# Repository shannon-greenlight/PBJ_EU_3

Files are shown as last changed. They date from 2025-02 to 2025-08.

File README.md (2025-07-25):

# The PBJ EU
The PBJ EU is a hardware development system for Eurorack synthesizers

Features:
- 800 point solderless proto board
- 4 switched 3.5mm jacks.
- Tip and Switch signals are routed from the jacks to the wiring connector.
- +/- 12V and adjustable A and B power rails are routed to the wiring connector.
- LED monitors for each jack. Red indicates positive voltage. Green indicates negative.
- 2 Test points per jack gives convenient access for probing and injecting signals.
- 2 Large Ground connection points are excellent for attaching alligator clips.
- 3 MULT switches connect jack 1 to 2, jack 2 to 3 or jack 3 to 4.
- Power is switched.
- Power indicators show the status of all power rails.
- 22 HP wide.
- Ready when you are. Everything you need with no pre-setup required!

# Making Changes
The process of making changes usually starts with altering the schematic followed by other actions as required.
This requires a properly configured KiCAD installation. Download the KiCAD [repo](https://github.com/shannon-greenlight/KiCAD) and follow the instructions in the README to install.
When the system is configured follow the steps outlined below. Some steps are optional depending on what has changed.

These procedures have been optimized for use with Digi-Key and JLCPCB. They should be a good starting point for use with other vendors.

- Update schematic
	- Update revision in File->Page Settings
	- Plot pdf version of schematic.
- If any parts have changed, Update BOMs
	- From KiCAD Schematic Editor, run Tools->Generate Legacy Bill of Materials using bom2grouped_csv.xsl
		- bom2grouped_csv.xsl is found in the Greenface KiCAD repo.
		- Here is a sample command line: xsltproc -o "%O.csv" "C:\Users\shann\Dropbox\KiCAD\bom2grouped_csv.xsl" "%I"
		- This creates a .csv and an xml file. The xml file is used in the next step.
	- Run _combine_boms.bat_
		- This creates the following .csv files
			- BOM\Digi-Key\PBJ_EU_combined.csv (all components, both boards combined)
			- BOM\Digi-Key\PBJ_EU_full.csv (all components, top board)
			- BOM\Digi-Key\PBJ_EU_split.csv (just components on top board that are not found in LCSC BOM)
			- BOM\LCSC\PBJ_EU_bom.csv (just components on top board to be assembled by JLCPCB)
			- sub\BOM\Digi-Key\PBJ_EU_full.csv (all components, sub board)
			- sub\BOM\Digi-Key\PBJ_EU_split.csv (just components on sub board that are not found in LCSC BOM)
			- sub\BOM\LCSC\PBJ_EU_bom.csv (just components on sub board to be assembled by JLCPCB)
		- combine_boms.bat requires Python and the Greenface Python [libraries](https://github.com/shannon-greenlight/PYTHON_BOM) to be installed
			- Place the Greenface Python folder in a convienient place on your computer and set the variable %plugin_dir% to point to that folder location.
			- Python is invoked as 'py' in the batch file. This may need to be changed depending on your Python installation.
- Update layout if required
	- Update revision in File->Page Settings
	- Plot the Gerber files
		- Set the output directory to _fab\gerber\\_
		- Make sure to Generate Drill Files
		- Create a zip archive of the Gerber files. (This is required by JLCPCB)
			- Use Windows Send To Compressed Folder. Rename the resulting file to PBJ_EU_gerbers.zip
			- Alternatively, use zip_gerbers.bat
			- zip_gerbers.bat requires 7z.exe
			- Edit this file if 7z.exe is installed somewhere other than C:\Program Files\7-Zip
	- Create the pick-and-place files
		- From KiCAD PCB Editor, run File->Fabrication Outputs->Component Placement
		- Set the output directory to _fab\pos\\_
		- This creates the files used by the next step
		- Update PBJ_EU_cpl.xlsx
			- PBJ_EU_cpl.xlsx uses Excel Queries to convert pos\PBJ_EU-top-pos.csv into a format compatible with JLCPCB
			- Excel requires an absolute path to the source folder of the data. Edit the query to enter the path to your project.
			- *note: This process does not produce a perfect placement file due to differences in how KiCAD and JLCPCB orient components. However, JLCPCB is able to use the file without problems. So, even if the placement looks wrong when specifying the build, they will use the file and produce correct boards.
			- **note: There is probably a KiCAD plugin available that does a better job. The user is encouraged to try this route and report the results back.
- Upload to JLCPCB
	- JLCPCB requires the following files:
		- fab\PBJ_EU_gerbers.zip
		- fab\PBJ_EU_cpl.xlsx (only needed for assembly)
		- bom\LCSC\PBJ_EU_bom.csv (only needed for assembly)

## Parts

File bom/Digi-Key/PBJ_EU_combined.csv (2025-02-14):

Reference | Quantity | Value | Digi-Key Part #
B1, B2, | 2 | Breadboard_400 | 1286-1185-ND
RV1, RV2, | 2 | 5K | 3296W-502LF-ND
SC1, SC2, SC3, SC4, | 4 | Mounting Screw | 335-1156-ND
TP1, TP2, TP3, TP4, TP5, TP6, TP7, TP8, | 8 | TestPoint | 36-5006-ND
SW4, | 1 | MFS201N-9-Z | 563-1565-ND
SO1, SO2, SO3, SO4, SO5, SO6, SO7, SO8, | 8 | LED Spacer | 732-11596-ND
D11, | 1 | RED LED | 732-5005-ND
D9, | 1 | GREEN LED | 732-5007-ND
D10, | 1 | YELLOW LED | 732-5010-ND
D12, | 1 | BLUE LED | 732-5011-ND
D1, D3, D5, D7, | 4 | LED_RG | 754-WP937SURKCGKW-ND
SW1, SW2, SW3, | 3 | SW_SPDT | EG1248-ND
J5, | 1 | Conn_02x06_Odd_Even | S2211EC-06-ND
J6, | 1 | Conn_02x08_Odd_Even_Female | S7111-ND

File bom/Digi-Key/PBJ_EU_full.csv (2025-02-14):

Reference | Quantity | Value | Digi-Key Part #
B1, B2, | 2 | Breadboard_400 | 1286-1185-ND
J1, | 1 | Conn_02x06_Odd_Even | S5715-ND
J6, | 1 | Conn_02x08_Odd_Even_Female | S7111-ND
SC1, SC2, SC3, SC4, | 4 | Mounting Screw | 335-1156-ND
TP1, TP2, TP3, TP4, TP5, TP6, TP7, TP8, | 8 | TestPoint | 36-5006-ND

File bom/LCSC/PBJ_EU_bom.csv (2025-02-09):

Designator | Comment | Footprint | JLCPCBPart#
J1, | Conn_02x06_Odd_Even | greenface:PinSocket_2x06_P2.54mm_Vertical_SMD_no_holes | C3975151

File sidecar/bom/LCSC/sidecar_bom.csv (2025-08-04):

Designator | Comment | Footprint | JLCPCBPart#
J1, J2, J3, J4, | Conn_02x03_Odd_Even | Connector_PinSocket_2.54mm:PinSocket_2x03_P2.54mm_Vertical | C2897404

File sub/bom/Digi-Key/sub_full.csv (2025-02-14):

Reference | Quantity | Value | Digi-Key Part #
C1, C4, C6, C7, C11, C12, | 6 | 100nF | 311-1088-1-ND
C2, C5, | 2 | 10uF | 1276-6455-1-ND
C3, C8, | 2 | 22uF | 1276-7092-1-ND
C9, C10, C13, C14, | 4 | 10nF | 490-4778-1-ND
D1, D3, D5, D7, | 4 | LED_RG | 754-WP937SURKCGKW-ND
D9, | 1 | GREEN LED | 732-5007-ND
D10, | 1 | YELLOW LED | 732-5010-ND
D11, | 1 | RED LED | 732-5005-ND
D12, | 1 | BLUE LED | 732-5011-ND
J5, | 1 | Conn_02x06_Odd_Even | S2211EC-06-ND
J6, | 1 | Conn_02x05_Odd_Even | S9169-ND
R1, R2, R5, R6, | 4 | 620 | 13-MFR-25FTE52-620RCT-ND
R3, R4, | 2 | 2.2K | 541-10449-1-ND
R7, R9, R13, R15, | 4 | 510 | P17401CT-ND
R8, R10, R11, R12, R14, R16, R17, R18, | 8 | 1M | 541-2803-1-ND
RV1, RV2, | 2 | 5K | 3296W-502LF-ND
SO1, SO2, SO3, SO4, SO5, SO6, SO7, SO8, | 8 | LED Spacer | 732-11596-ND
SW1, SW2, SW3, | 3 | SW_SPDT | EG1248-ND
SW4, | 1 | MFS201N-9-Z | 563-1565-ND
U1, U3, | 2 | LM317 | 4518-LM317DCYRCT-ND
U2, U4, | 2 | TL072CDR | 296-1282-1-ND

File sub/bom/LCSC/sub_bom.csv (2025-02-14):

Designator | Comment | Footprint | JLCPCBPart#
C1, C4, C6, C7, C11, C12, | 100nF | Capacitor_SMD:C_0603_1608Metric | C14663
C2, C5, | 10uF | Capacitor_SMD:C_0805_2012Metric_Pad1.18x1.45mm_HandSolder | C15850
C3, C8, | 22uF | Capacitor_SMD:C_0805_2012Metric_Pad1.18x1.45mm_HandSolder | C76637
C9, C10, C13, C14, | 10nF | Capacitor_SMD:C_0603_1608Metric | C1589
J6, | Conn_02x05_Odd_Even | Connector_PinHeader_2.54mm:PinHeader_2x05_P2.54mm_Vertical | C492422
R1, R2, R5, R6, | 620 | Resistor_SMD:R_0603_1608Metric | C23220
R3, R4, | 2.2K | Resistor_SMD:R_0603_1608Metric | C4190
R7, R9, R13, R15, | 510 | Resistor_SMD:R_0603_1608Metric | C23193
R8, R10, R11, R12, R14, R16, R17, R18, | 1M | Resistor_SMD:R_0603_1608Metric | C22935
U1, U3, | LM317 | Package_TO_SOT_SMD:SOT-223-3_TabPin2 | C51466
U2, U4, | TL072CDR | Package_SO:SOIC-8_3.9x4.9mm_P1.27mm | C6961

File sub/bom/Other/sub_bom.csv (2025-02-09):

Designator | Comment | Footprint | Other
D9, | GREEN LED | LED_THT:LED_D3.0mm | https://www.amazon.com/dp/B077J2WJRS/
D10, | YELLOW LED | LED_THT:LED_D3.0mm | https://www.amazon.com/dp/B077J2WJRS/
D11, | RED LED | LED_THT:LED_D3.0mm | https://www.amazon.com/dp/B077J2WJRS/
D12, | BLUE LED | LED_THT:LED_D3.0mm | https://www.amazon.com/dp/B077J2WJRS/
J1, J2, J3, J4, | Thonk 3.5mm Jack | greenface:Jack_3.5mm_QingPu_WQP-PJ398SM_Vertical | https://synthcube.com/cart/3.5mm-audio-jacks

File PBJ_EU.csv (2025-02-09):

Reference | Quantity | Value | Footprint | Datasheet | Digi-Key Part | LCSC Part #
B1 B2 | 2 | Breadboard_400 | panel:Proto_400 |  | 1286-1185-ND
C1 C5 | 2 | 10uF | Capacitor_THT:CP_Radial_D5.0mm_P2.00mm |  | 732-8820-1-ND | C88726
C13 C14 C15 C16 | 4 | 10nF | Capacitor_THT:C_Rect_L7.0mm_W2.0mm_P5.00mm | http://datasheets.avx.com/SR-Series.pdf | BC2662CT-ND | C263180
C2 C6 C7 C8 C10 C11 | 6 | .1uF | Capacitor_THT:C_Rect_L7.0mm_W2.0mm_P5.00mm |  | 478-3188-ND | C84772
C4 C12 | 2 | 22uF | Capacitor_THT:CP_Radial_D5.0mm_P2.00mm |  | 732-8733-1-ND | C43346
J1 | 1 | Conn_02x10_Odd_Even_Male | Connector_PinHeader_2.54mm:PinHeader_2x10_P2.54mm_Vertical |  | S2011EC-10-ND | C492427
J6 | 1 | Conn_02x08_Odd_Even_Female | Connector_PinHeader_2.54mm:PinHeader_2x08_P2.54mm_Vertical |  | S7111-ND
J7 | 1 | Conn_02x05_Odd_Even | Connector_PinHeader_2.54mm:PinHeader_2x05_P2.54mm_Vertical |  | S2011EC-05-ND
JC1 | 1 | Eurorack Power Cable |  |  | H3CCS-1018G-ND
R1 R2 R3 R4 R6 R7 R8 R9 | 8 | 5.6K | Resistor_THT:R_Axial_DIN0207_L6.3mm_D2.5mm_P10.16mm_Horizontal |  | CF14JT5K60CT-ND | C119341
R10 R11 R12 R13 | 4 | 1M | Resistor_THT:R_Axial_DIN0207_L6.3mm_D2.5mm_P10.16mm_Horizontal |  | CF14JT1M00CT-ND | C433776
R17 R18 | 2 | 620 | Resistor_THT:R_Axial_DIN0207_L6.3mm_D2.5mm_P10.16mm_Horizontal |  | 13-MFR-25FTE52-620RCT-ND | C713992
RV1 RV2 | 2 | 5K | Potentiometer_THT:Potentiometer_Bourns_3296W_Vertical |  | 3296W-502LF-ND | C60620
SC1 SC2 SC3 SC4 | 4 | Mounting Screw |  |  | 335-1156-ND
SK1 SK2 | 2 | A_08-LC-TT | Package_DIP:DIP-8_W7.62mm_Socket_LongPads | http://www.assmann-wsw.com/fileadmin/datasheets/ASS_0810_CO.pdf | 609-4717-ND
TP1 TP2 TP3 TP4 TP9 TP10 TP11 | 7 | TestPoint | TestPoint:TestPoint_Keystone_5005-5009_Compact |  | 36-5006-ND
TP5 TP6 TP7 TP8 | 4 | TestPoint | 16ga solid wire
U1 U2 | 2 | TL072 | Package_DIP:DIP-8_W7.62mm_Socket_LongPads | http://www.ti.com/lit/ds/symlink/tl071.pdf | 296-1775-5-ND | C72124
U3 U4 | 2 | LM317_TO-220 | Package_TO_SOT_THT:TO-220-3_Vertical | http://www.ti.com/lit/ds/symlink/lm317.pdf | 497-19621-ND | C14502

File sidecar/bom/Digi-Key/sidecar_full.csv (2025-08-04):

Reference | Quantity | Value | Digi-Key Part #
J1, J2, J3, J4, | 4 | Conn_02x03_Odd_Even | S7071-ND

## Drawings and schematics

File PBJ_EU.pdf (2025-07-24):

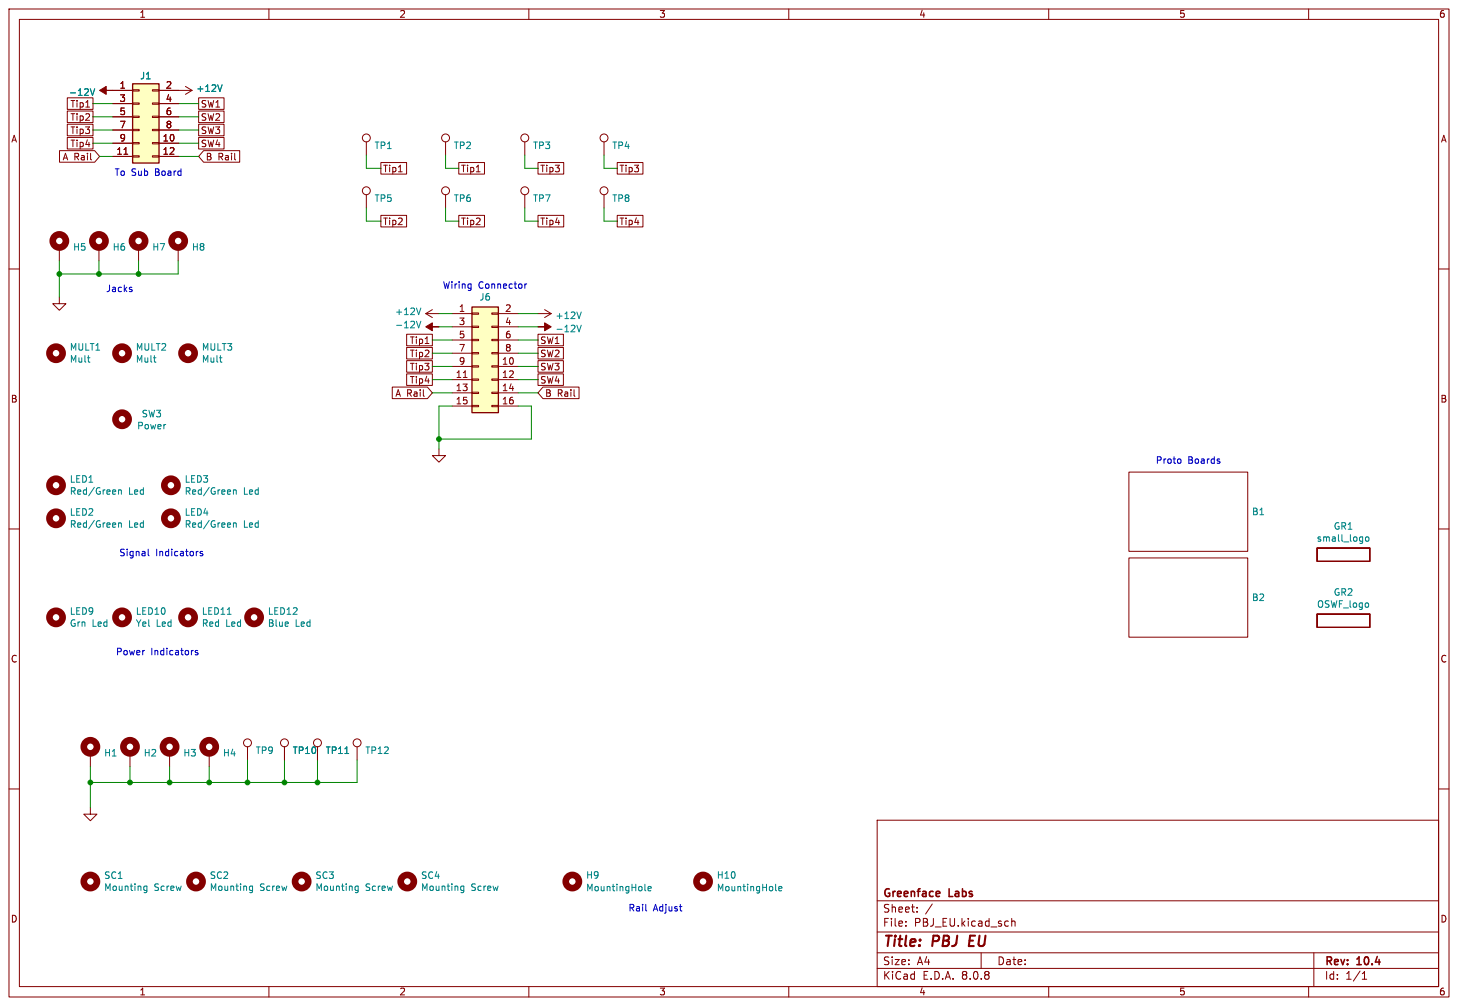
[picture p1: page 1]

Jacks To Sub Board

Id: 1/1 Title: PBJ EU

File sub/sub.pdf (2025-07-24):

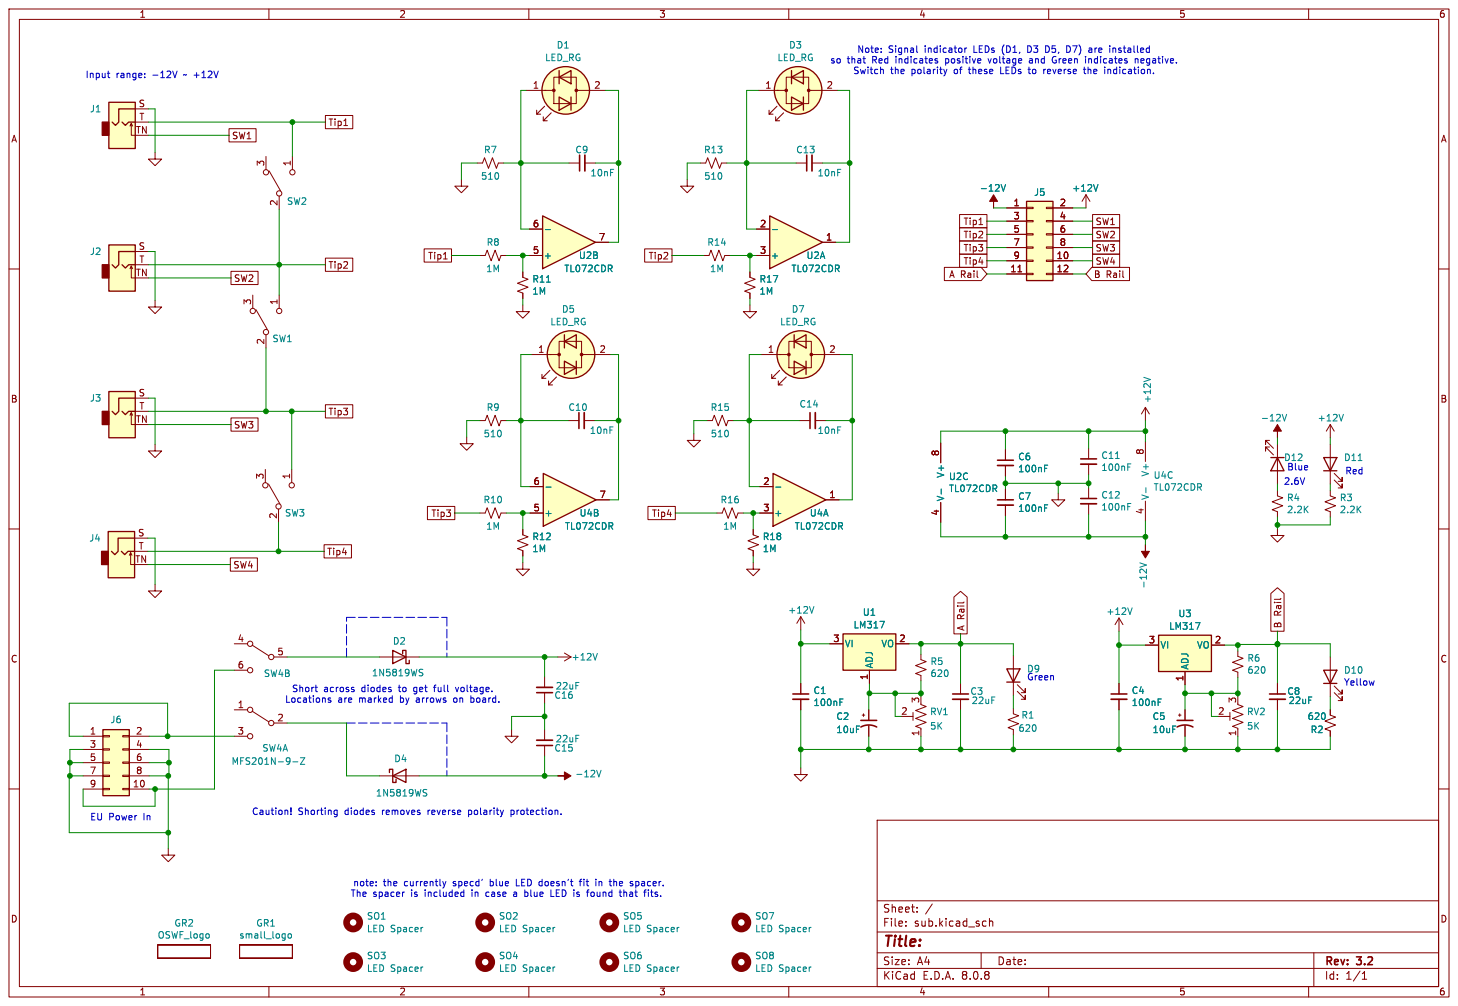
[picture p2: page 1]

Id: 1/1 Title: File: sub.kicad_sch Sheet: / SO7

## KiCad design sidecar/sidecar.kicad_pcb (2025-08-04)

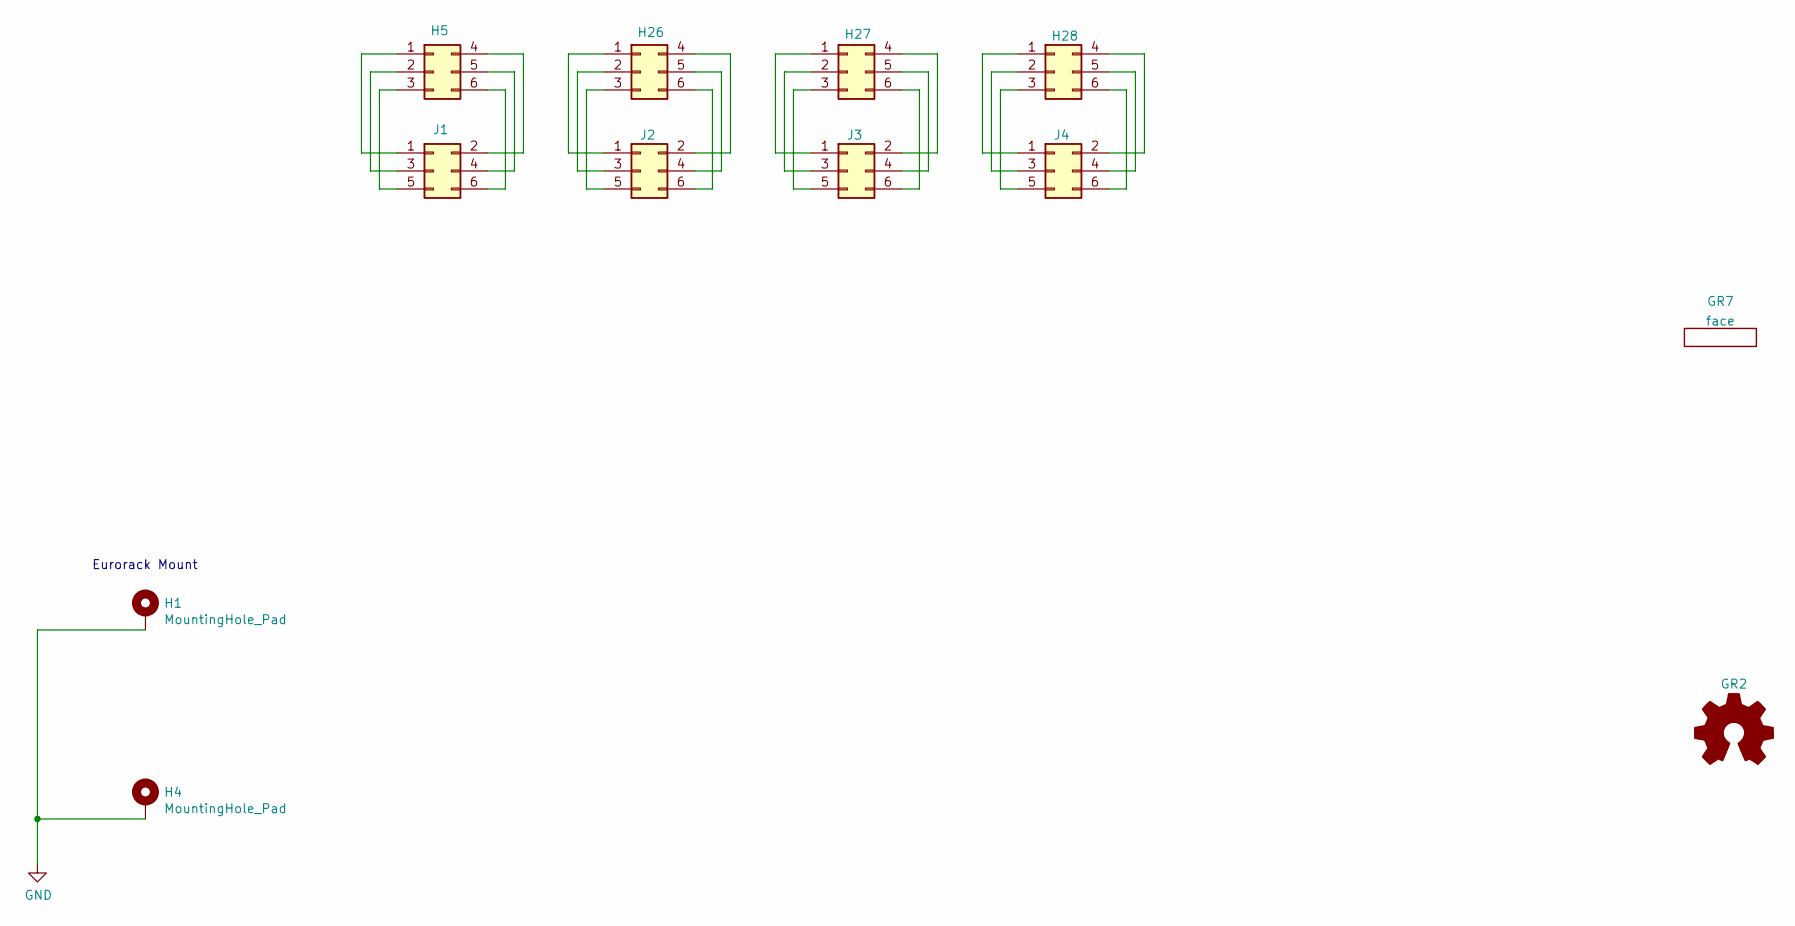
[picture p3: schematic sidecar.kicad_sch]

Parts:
GR2: Logo_Open_Hardware_Small; OSHW-Logo_5.7x6mm_SilkScreen
GR7: face; small_face
H1, H4: MountingHole_Pad; MountingHole_3.2mm_M3_Slot
H5: Adj 1; Potentiometer_Sidecar
H26: Adj 2; Potentiometer_Sidecar
H27: Adj 3; Potentiometer_Sidecar
H28: Adj 4; Potentiometer_Sidecar
J1, J2, J3, J4: Conn_02x03_Odd_Even; PinSocket_2x03_P2.54mm_Vertical; Digi-Key Part S7071-ND

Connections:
GND: H1.1, H4.1
unnamed: H5.1, J1.1
unnamed: H5.2, J1.3
unnamed: H5.3, J1.5
unnamed: H5.4, J1.2
unnamed: H5.5, J1.4
unnamed: H5.6, J1.6
unnamed: H26.1, J2.1
unnamed: H26.2, J2.3
unnamed: H26.3, J2.5
unnamed: H26.4, J2.2
unnamed: H26.5, J2.4
unnamed: H26.6, J2.6
unnamed: H27.1, J3.1
unnamed: H27.2, J3.3
unnamed: H27.3, J3.5
unnamed: H27.4, J3.2
unnamed: H27.5, J3.4
unnamed: H27.6, J3.6
unnamed: H28.1, J4.1
unnamed: H28.2, J4.3
unnamed: H28.3, J4.5
unnamed: H28.4, J4.2
unnamed: H28.5, J4.4
unnamed: H28.6, J4.6

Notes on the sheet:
Eurorack Mount

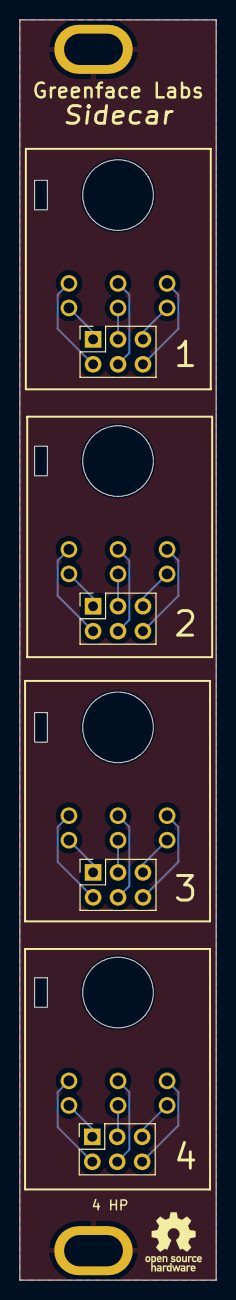
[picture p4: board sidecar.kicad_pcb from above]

Board: 2 copper layers, 20.0 x 128.4 mm, 11 parts (0 on the bottom side), 25 nets.

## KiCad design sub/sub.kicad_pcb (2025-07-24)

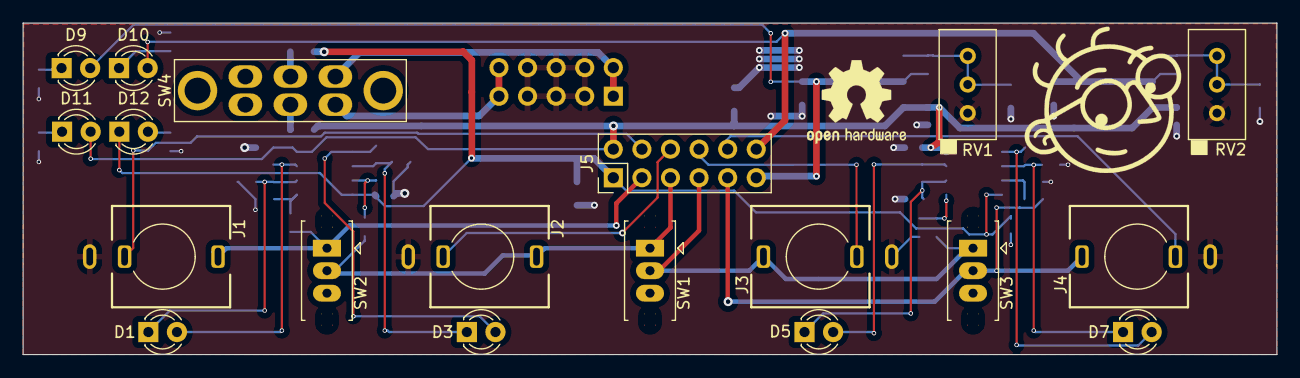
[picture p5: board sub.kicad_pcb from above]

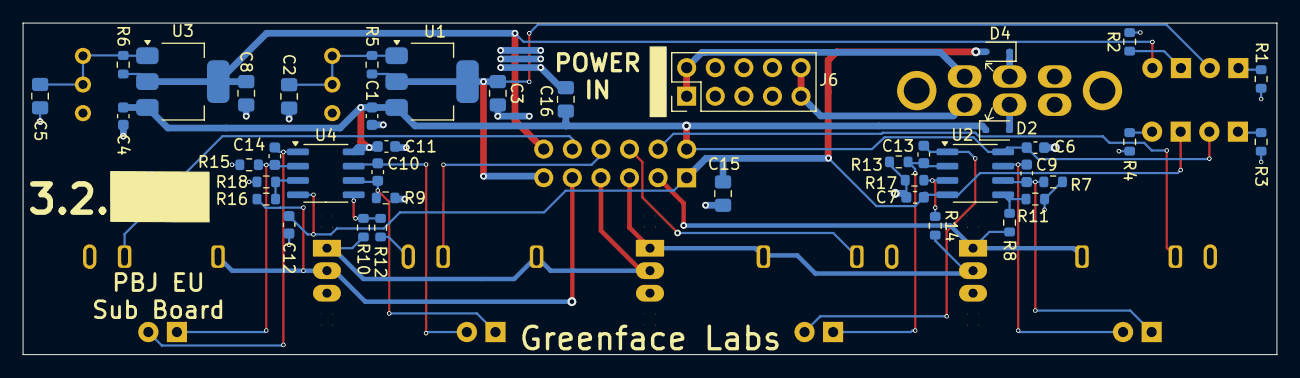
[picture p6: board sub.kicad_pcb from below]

Board: 2 copper layers, 111.4 x 29.4 mm, 62 parts (41 on the bottom side), 35 nets.

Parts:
C1, C4, C6, C7, C11, C12: 100nF; C_0603_1608Metric
C2, C5: 10uF; C_0805_2012Metric_Pad1.18x1.45mm_HandSolder
C3, C8, C15, C16: 22uF; C_0805_2012Metric_Pad1.18x1.45mm_HandSolder
C9, C10, C13, C14: 10nF; C_0603_1608Metric
D1, D3, D5, D7: LED_RG; LED_D3.0mm
D2, D4: 1N5819WS; D_SOD-323
D9: GREEN LED; LED_D3.0mm
D10: YELLOW LED; LED_D3.0mm
D11: RED LED; LED_D3.0mm
D12: BLUE LED; LED_D3.0mm
GR1: small_logo; small_face
GR2: OSWF_logo; OSHW-Logo2_9.8x8mm_SilkScreen
J1, J2, J3, J4: Thonk 3.5mm Jack; Jack_3.5mm_QingPu_WQP-PJ398SM_Vertical
J5: Conn_02x06_Odd_Even; PinHeader_2x06_P2.54mm_Vertical
J6: Conn_02x05_Odd_Even; PinHeader_2x05_P2.54mm_Vertical
R1, R2, R5, R6: 620; R_0603_1608Metric
R3, R4: 2.2K; R_0603_1608Metric
R7, R9, R13, R15: 510; R_0603_1608Metric
R8, R10, R11, R12, R14, R16, R17, R18: 1M; R_0603_1608Metric
RV1, RV2: 5K; Potentiometer_Bourns_3296W_Vertical
SW1, SW2, SW3: SW_SPDT; SW_Slide_EG1248
SW4: MFS201N-9-Z; MFS201N−9−Z
U1, U3: LM317; SOT-223-3_TabPin2
U2, U4: TL072CDR; SOIC-8_3.9x4.9mm_P1.27mm

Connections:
+12V: C1.1, C4.1, C6.1, C11.1, C16.2, D2.1 (K), D11.2 (A), J5.2, U1.3 (VI), U2.8 (V+), U3.3 (VI), U4.8 (V+)
-12V: C7.2, C12.2, C15.1, D4.2 (A), D12.1 (K), J5.1, U2.4 (V-), U4.4 (V-)
A Rail: C3.1, D9.2 (A), J5.11, R5.1, U1.2 (VO)
B Rail: C8.1, D10.2 (A), J5.12, R6.1, U3.2 (VO)
GND: C1.2, C2.2, C3.2, C4.2, C5.2, C6.2, C7.1, C8.2, C11.2, C12.1, C15.2, C16.1, J1.S, J2.S, J3.S, J4.S, J6.3, J6.4, J6.5, J6.6, J6.7, J6.8, R1.1, R2.2, R3.2, R4.2, R7.1, R9.1, R11.2, R12.2, R13.1, R15.1, R17.2, R18.2, RV1.1, RV2.1
unnamed: C9.2, D1.2 (AK), U2.7
unnamed: C9.1, D1.1 (KA), R7.2, U2.6 (-)
unnamed: D2.2 (A), SW4.5 (B)
unnamed: C13.2, D3.2 (AK), U2.1
unnamed: C13.1, D3.1 (KA), R13.2, U2.2 (-)
unnamed: D4.1 (K), SW4.2 (B)
unnamed: C10.2, D5.2 (AK), U4.7
unnamed: C10.1, D5.1 (KA), R9.2, U4.6 (-)
unnamed: C14.2, D7.2 (AK), U4.1
unnamed: C14.1, D7.1 (KA), R15.2, U4.2 (-)
unnamed: D9.1 (K), R1.2
unnamed: D10.1 (K), R2.1
unnamed: D11.1 (K), R3.1
unnamed: D12.2 (A), R4.1
unnamed: J6.1, J6.2, SW4.3 (C)
unnamed: J6.9, J6.10, SW4.6 (C)
unnamed: C2.1, R5.2, RV1.2, RV1.3, U1.1 (ADJ)
unnamed: R14.1, R17.1, U2.3 (+)
unnamed: R8.1, R11.1, U2.5 (+)
unnamed: C5.1, R6.2, RV2.2, RV2.3, U3.1 (ADJ)
unnamed: R16.1, R18.1, U4.3 (+)
unnamed: R10.1, R12.1, U4.5 (+)
SW1: J1.TN, J5.4
SW2: J2.TN, J5.6
SW3: J3.TN, J5.8
SW4: J4.TN, J5.10
Tip1: J1.T, J5.3, R8.2, SW2.1 (A)
Tip2: J2.T, J5.5, R14.2, SW1.1 (A), SW2.2 (B)
Tip3: J3.T, J5.7, R10.2, SW1.2 (B), SW3.1 (A)
Tip4: J4.T, J5.9, R16.2, SW3.2 (B)

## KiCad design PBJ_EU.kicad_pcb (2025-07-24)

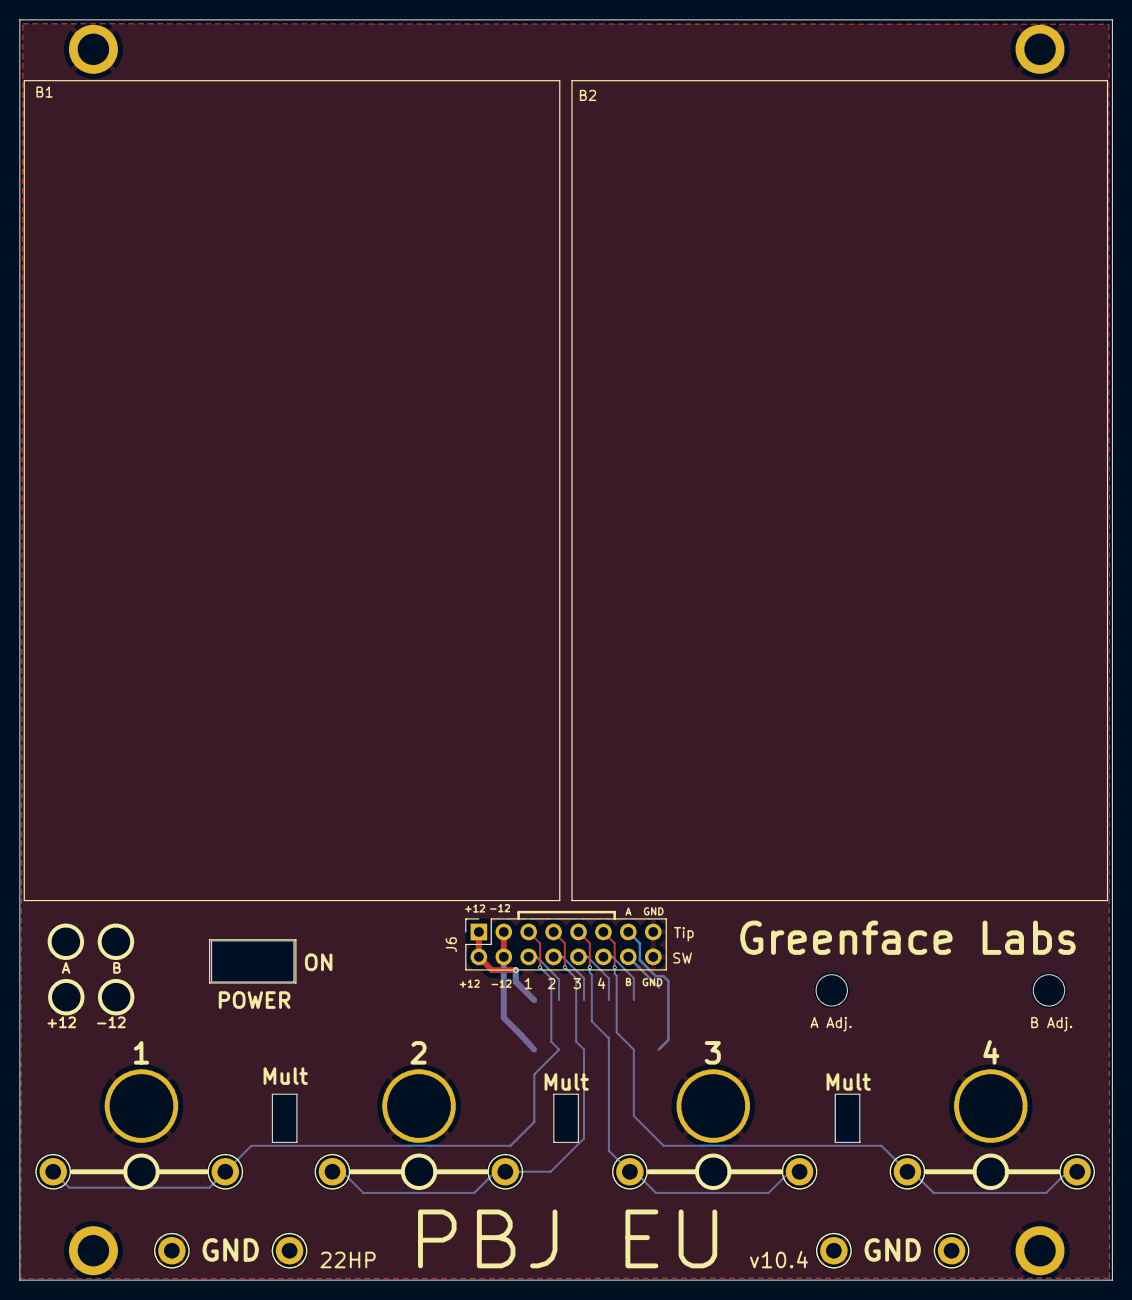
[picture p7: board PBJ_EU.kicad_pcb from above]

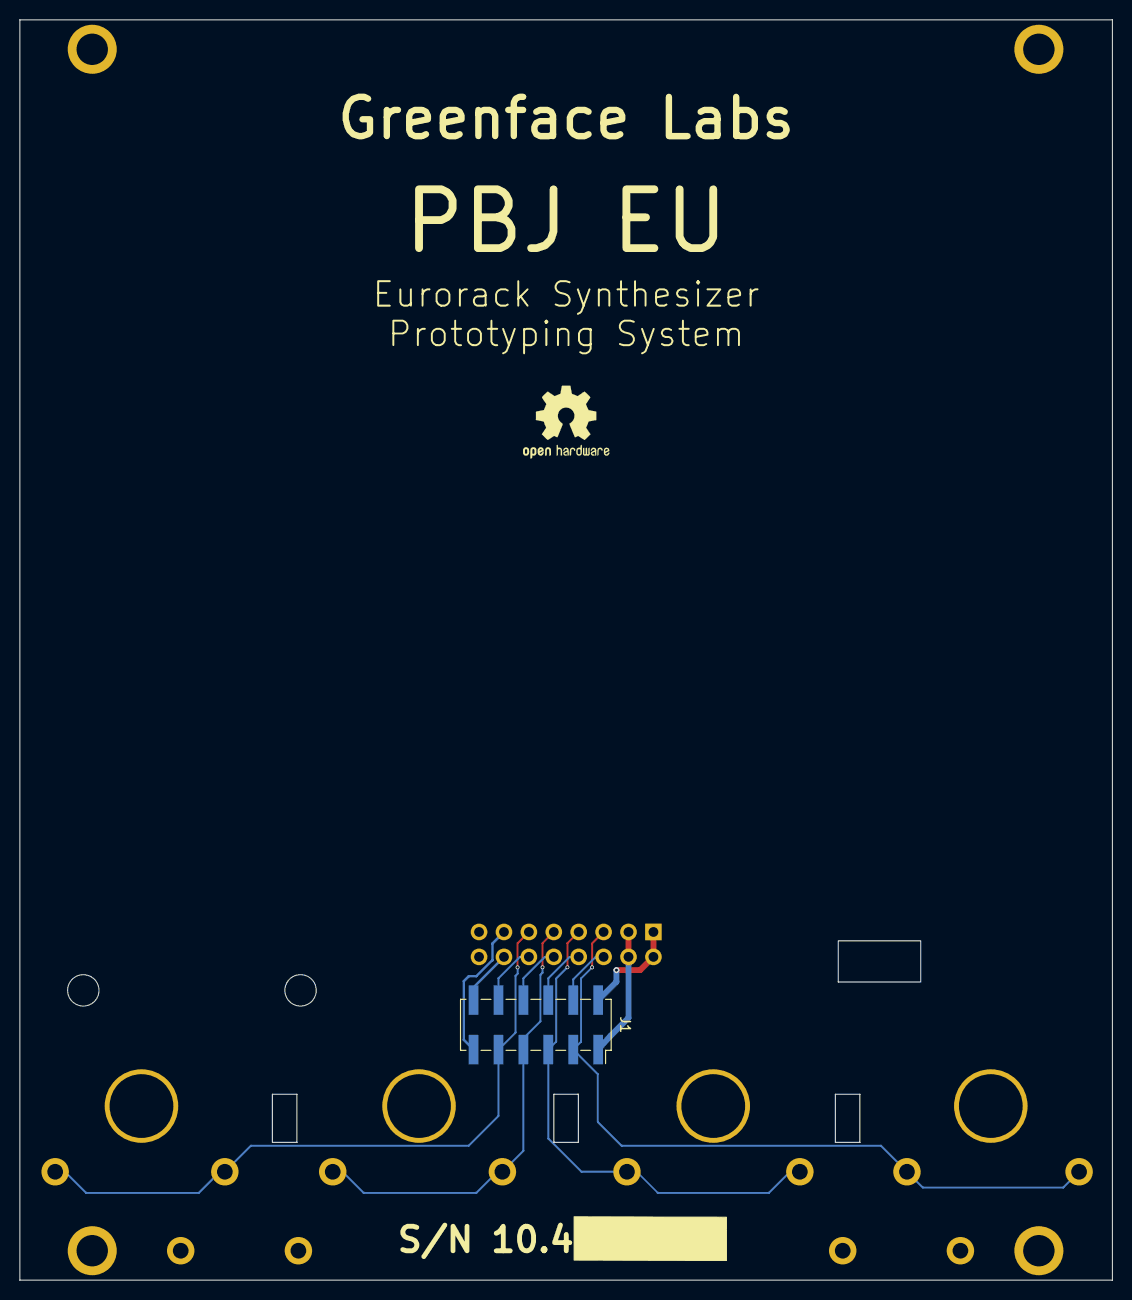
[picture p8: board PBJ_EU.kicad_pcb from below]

Board: 2 copper layers, 111.4 x 128.5 mm, 39 parts (2 on the bottom side), 13 nets.

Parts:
B1, B2: Breadboard_400; Proto_400
GR2: OSWF_logo; OSHW-Logo2_9.8x8mm_SilkScreen
H1, H2, H3, H4: MountingHole_Pad; MountingHole_3.2mm_M3_SmPad
H5, H6, H7, H8: MountingHole_Pad; Jack_3.5mm_QingPu_WQP-PJ398SM_Vertical
H9, H10: MountingHole; MountingHole_3.2mm_M3
J1: Conn_02x06_Odd_Even; PinSocket_2x06_P2.54mm_Vertical_SMD_no_holes
J6: Conn_02x08_Odd_Even_Female; PinSocket_2x08_P2.54mm_Vertical
LED1, LED2, LED3, LED4: Red/Green Led; 3mmLED_seethru_small
LED9: Grn Led; 3mmLED_seethru_small
LED10: Yel Led; 3mmLED_seethru_small
LED11: Red Led; 3mmLED_seethru_small
LED12: Blue Led; 3mmLED_seethru_small
MULT1, MULT2, MULT3: Mult; EG1248
SW3: Power; MFS201N−9−Z
TP1, TP2, TP3, TP4, TP5, TP6, TP7, TP8, TP9, TP10, TP11, TP12: TestPoint; TestPoint_Keystone_5005-5009_Compact

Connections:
+12V: J1.2, J6.1, J6.2
-12V: J1.1, J6.3, J6.4
A Rail: J1.11, J6.13
B Rail: J1.12, J6.14
GND: H1.1, H2.1, H3.1, H4.1, H5.1, H6.1, H7.1, H8.1, J6.15, J6.16, TP9.1, TP10.1, TP11.1, TP12.1
SW1: J1.4, J6.6
SW2: J1.6, J6.8
SW3: J1.8, J6.10
SW4: J1.10, J6.12
Tip1: J1.3, J6.5, TP1.1, TP2.1
Tip2: J1.5, J6.7, TP5.1, TP6.1
Tip3: J1.7, J6.9, TP3.1, TP4.1
Tip4: J1.9, J6.11, TP7.1, TP8.1

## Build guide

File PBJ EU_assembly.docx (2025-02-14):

# PBJ EU Assembly Instructions

This document assumes assembly from bare boards or partially assembled boards. Skip step 3 if you have partially assembled boards.

Because of the density of the circuitry, a conical .8mm tip soldering iron is suggested.

Difficulty: beginner. OK for first build.

1. Assemble main board first.
2. Install test points and wiring connector J6 to the top side of the main board.
3. Use solid 14ga wire to make GND bars from test points 9-12.
4. Install SMD mating connector to the bottom side of the main board.
5. Assemble sub board next.
6. Install SMD components and power connector on the bottom side of sub board.
7. Install all components except LEDs on top side of sub board.
8. Place LEDs with stand-offs into sub board and mate the sub board with the main board.
9. Solder LEDs while adjusting their position to match the windows on the main board.
10. Install proto-boards. They lock together for a tight fit. You can do this before fixing them to the board.
11. That’s all! You’re ready to start developing awesome synth circuitry the easy way.

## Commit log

2025-02-09 Init checkin
    [PBJ_EU-B_Cu.gbr, PBJ_EU-B_Mask.gbr, PBJ_EU-B_Paste.gbr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]
2025-02-14 Adds mention of GND bar.
2025-07-24 v 10.4
    [PBJ_EU-B_Cu.gbr, PBJ_EU-B_Mask.gbr, PBJ_EU-B_Paste.gbr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]
2025-07-24 Removes Other from BOMS
    [PBJ_EU_bom.csv]
2025-08-04 Adds Sidecar v0.1
    [sidecar-B_Adhesive.gbr, sidecar-B_Cu.gbr, sidecar-B_Mask.gbr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]
